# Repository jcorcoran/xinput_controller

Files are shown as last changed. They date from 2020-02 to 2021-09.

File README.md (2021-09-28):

# xinput_controller

## Installation

Getting the xinput libraries working is a bit of a process.
Last tested with the following software baslines:
  - Teensyduino 1.50: https://www.pjrc.com/teensy/td_150/TeensyduinoInstall.exe
  - Arduino 1.8.11: https://www.arduino.cc/en/main/OldSoftwareReleases
  - ArduinoXInput_Teensy 1.0.6: https://github.com/dmadison/ArduinoXInput_Teensy/releases
  - ArduinoXInput v1.2.1: https://github.com/dmadison/ArduinoXInput  (installable through ARduino Tools > Manage Libraries)
 
Follow the installation instructions for ArduinoXInput library found [in its repo](https://github.com/dmadison/ArduinoXInput_Teensy)

## PCB

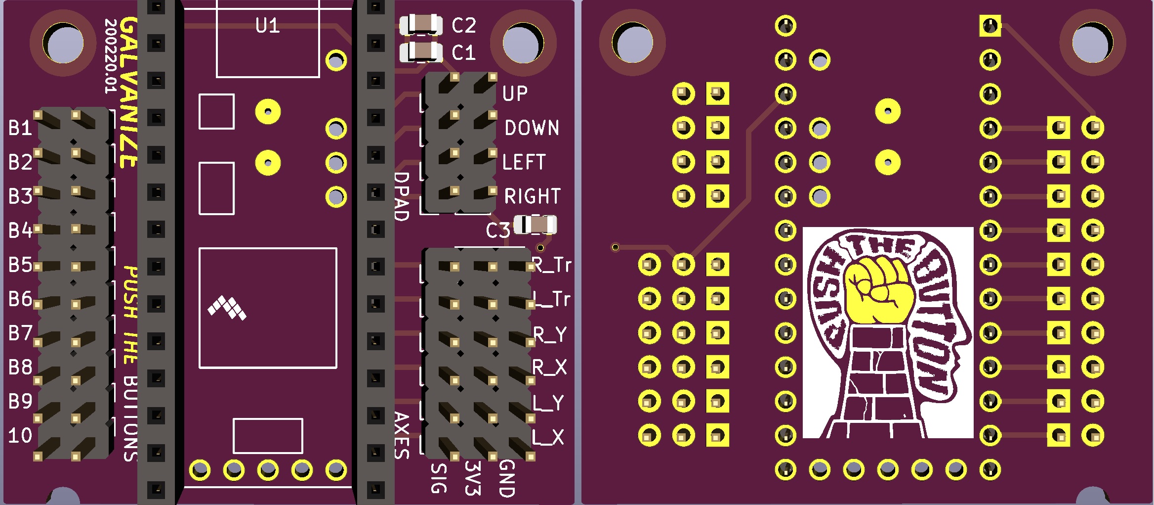
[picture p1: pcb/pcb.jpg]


* KiCAD project files and gerbers are [here](https://github.com/jcorcoran/xinput_controller/tree/master/pcb/galvanize)
* Also available for easy one-click ordering from: https://oshpark.com/shared_projects/lwcYD8mQ

Generic breakout board for a typical xinput device that provides the following on 0.1" pitch headers:
   * 10x discrete button input channels
   * 4x discrete D-Pad inputs (Up, Down, Left, Right)
   * 6x analog input channels (Right Axis X & Y, Left Axis X & Y, Left & Right Triggers)

### Bill of materials:

  * 1x - Teensy LC
  * 2x - 1x14 0.1" pitch female pin headers
  * 14x - 1x2 0.1" pitch male pin headers
  * 6x - 1x3 0.1" pitch male pin headers
  * C1, C2, C3 filter caps are optional

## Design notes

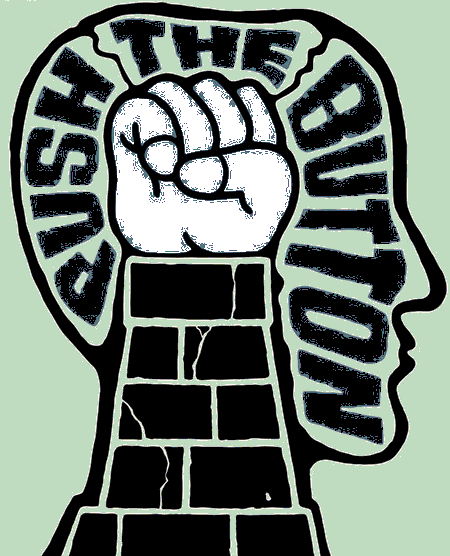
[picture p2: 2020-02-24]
pcb/galvanize/push_The_button.bmp

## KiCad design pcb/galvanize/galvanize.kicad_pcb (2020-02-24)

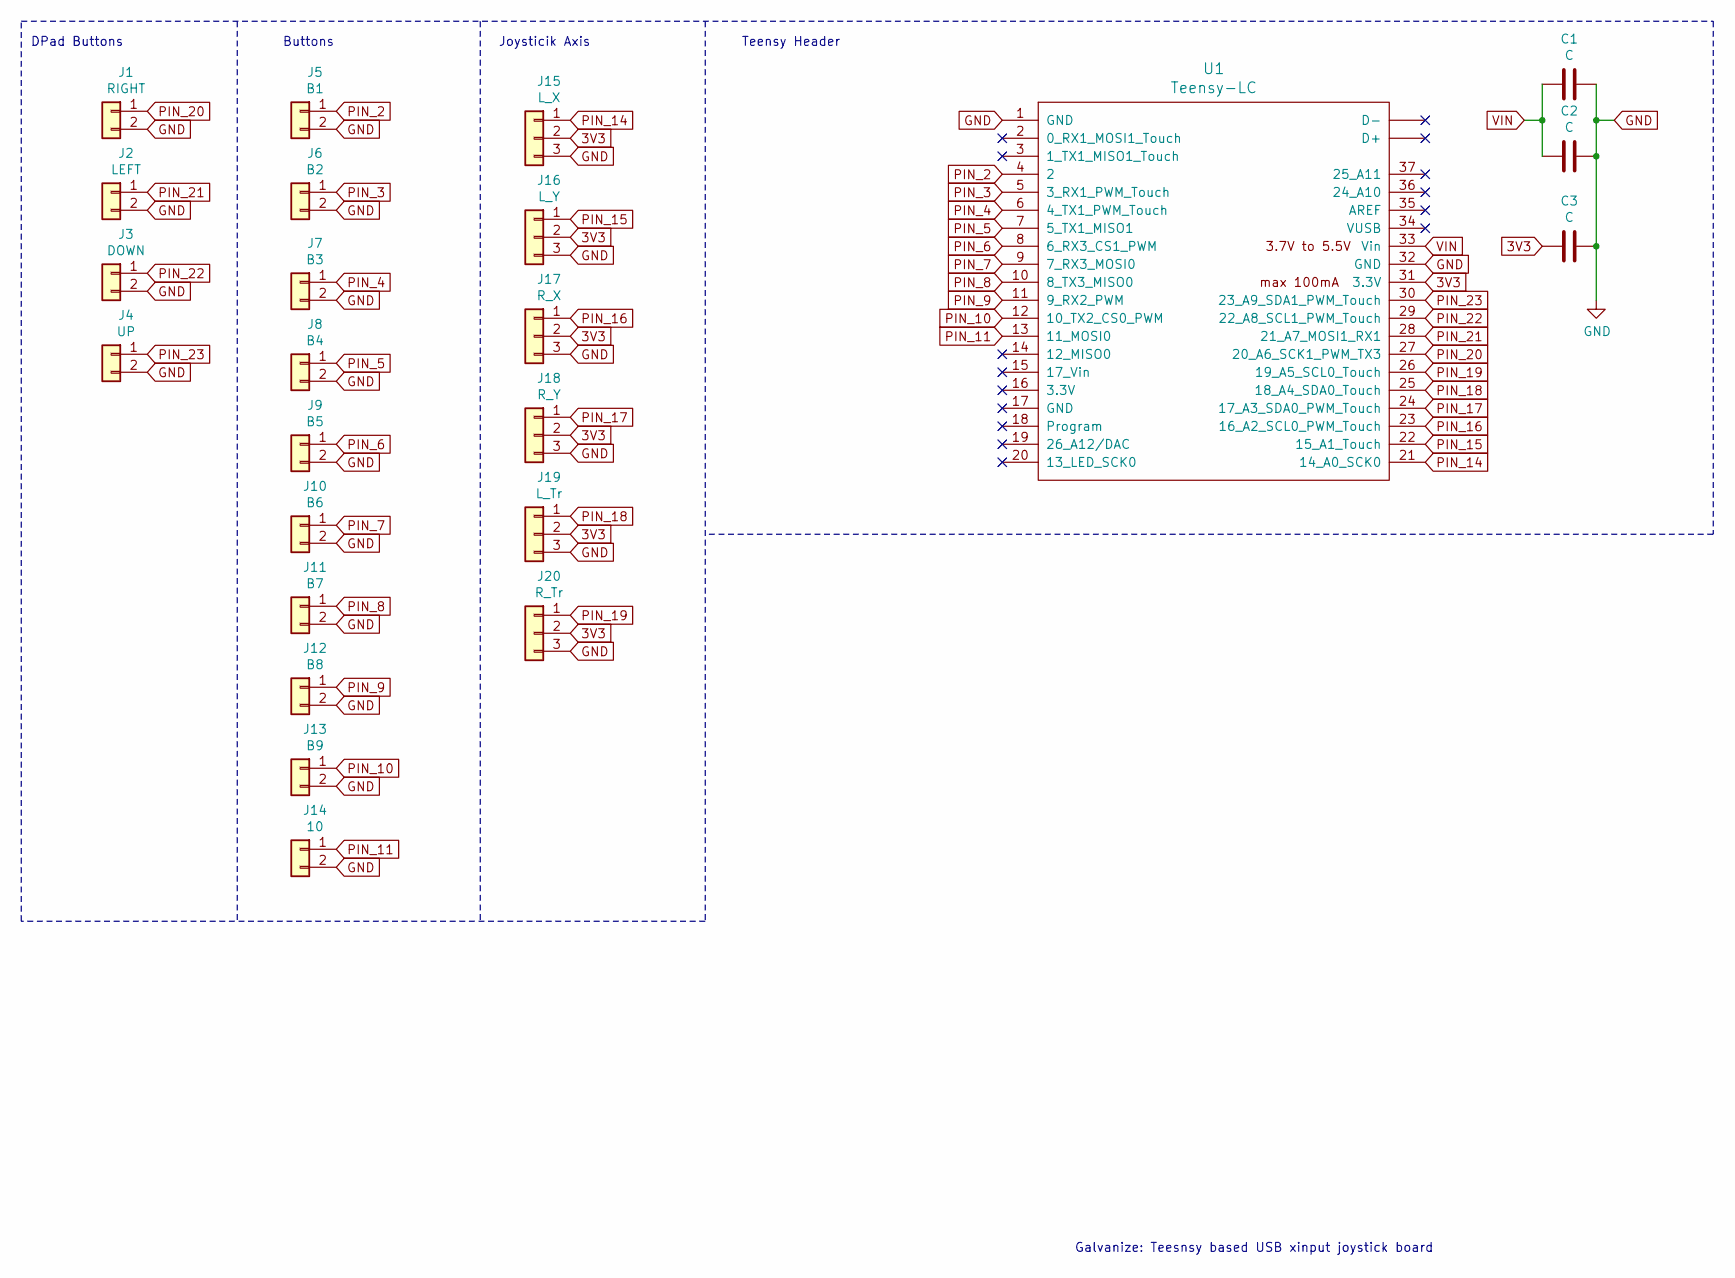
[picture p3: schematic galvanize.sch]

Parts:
C1, C2, C3: C; C_0805_2012Metric_Pad1.15x1.40mm_HandSolder
J1: RIGHT; PinHeader_1x02_P2.54mm_Vertical_Labeled
J2: LEFT; PinHeader_1x02_P2.54mm_Vertical_Labeled
J3: DOWN; PinHeader_1x02_P2.54mm_Vertical_Labeled
J4: UP; PinHeader_1x02_P2.54mm_Vertical_Labeled
J5: B1; PinHeader_1x02_P2.54mm_Vertical_Labeled
J6: B2; PinHeader_1x02_P2.54mm_Vertical_Labeled
J7: B3; PinHeader_1x02_P2.54mm_Vertical_Labeled
J8: B4; PinHeader_1x02_P2.54mm_Vertical_Labeled
J9: B5; PinHeader_1x02_P2.54mm_Vertical_Labeled
J10: B6; PinHeader_1x02_P2.54mm_Vertical_Labeled
J11: B7; PinHeader_1x02_P2.54mm_Vertical_Labeled
J12: B8; PinHeader_1x02_P2.54mm_Vertical_Labeled
J13: B9; PinHeader_1x02_P2.54mm_Vertical_Labeled
J14: 10; PinHeader_1x02_P2.54mm_Vertical_Labeled
J15: L_X; PinHeader_1x03_P2.54mm_Vertical_Labeled
J16: L_Y; PinHeader_1x03_P2.54mm_Vertical_Labeled
J17: R_X; PinHeader_1x03_P2.54mm_Vertical_Labeled
J18: R_Y; PinHeader_1x03_P2.54mm_Vertical_Labeled
J19: L_Tr; PinHeader_1x03_P2.54mm_Vertical_Labeled
J20: R_Tr; PinHeader_1x03_P2.54mm_Vertical_Labeled
U1: Teensy-LC; Teensy30_31_32_LC

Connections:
3V3: C3.2, J15.2, J16.2, J17.2, J18.2, J19.2, J20.2, U1.31 (3.3V)
GND: C1.1, C2.1, C3.1, J1.2, J2.2, J3.2, J4.2, J5.2, J6.2, J7.2, J8.2, J9.2, J10.2, J11.2, J12.2, J13.2, J14.2, J15.3, J16.3, J17.3, J18.3, J19.3, J20.3, U1.1 (GND), U1.32 (GND)
PIN_2: J5.1, U1.4 (2)
PIN_3: J6.1, U1.5 (3_RX1_PWM_Touch)
PIN_4: J7.1, U1.6 (4_TX1_PWM_Touch)
PIN_5: J8.1, U1.7 (5_TX1_MISO1)
PIN_6: J9.1, U1.8 (6_RX3_CS1_PWM)
PIN_7: J10.1, U1.9 (7_RX3_MOSI0)
PIN_8: J11.1, U1.10 (8_TX3_MISO0)
PIN_9: J12.1, U1.11 (9_RX2_PWM)
PIN_10: J13.1, U1.12 (10_TX2_CS0_PWM)
PIN_11: J14.1, U1.13 (11_MOSI0)
PIN_14: J15.1, U1.21 (14_A0_SCK0)
PIN_15: J16.1, U1.22 (15_A1_Touch)
PIN_16: J17.1, U1.23 (16_A2_SCL0_PWM_Touch)
PIN_17: J18.1, U1.24 (17_A3_SDA0_PWM_Touch)
PIN_18: J19.1, U1.25 (18_A4_SDA0_Touch)
PIN_19: J20.1, U1.26 (19_A5_SCL0_Touch)
PIN_20: J1.1, U1.27 (20_A6_SCK1_PWM_TX3)
PIN_21: J2.1, U1.28 (21_A7_MOSI1_RX1)
PIN_22: J3.1, U1.29 (22_A8_SCL1_PWM_Touch)
PIN_23: J4.1, U1.30 (23_A9_SDA1_PWM_Touch)
VIN: C1.2, C2.2, U1.33 (Vin)

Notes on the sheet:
DPad Buttons
Buttons
Joysticik Axis
Teensy Header
Galvanize: Teesnsy based USB xinput joystick board

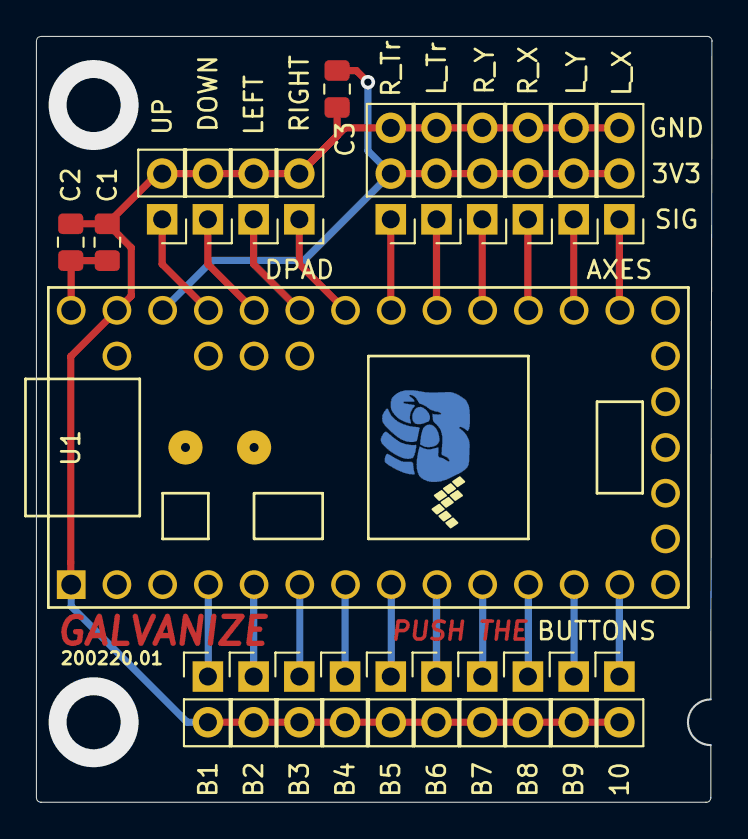
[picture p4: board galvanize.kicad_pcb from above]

Board: 2 copper layers, 37.5 x 42.5 mm, 24 parts (0 on the bottom side), 23 nets.

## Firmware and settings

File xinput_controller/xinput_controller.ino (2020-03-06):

/**
 * xinput_controller
 *
 * Intended for FRC use as a generic joystick/button box platform.
 *
 * based on flight stick example from:
 * https://github.com/dmadison/MSF-XINPUT/blob/master/MSF_XINPUT/examples/MSF_FightStick/MSF_FightStick.ino
 *
 **/

//Includes
#include <Bounce.h>
#include <XInput.h>

//General Declarations
#define MILLIDEBOUNCE 20  //Debounce time in milliseconds
#define NUMBUTTONS 14     //Number of all buttons (including d-pad)
#define NUMBUTTONSONLY 10 //Number of non-dpad buttons 

//Digital Pin Declarations
#define pinUP 23     //Up on stick pin
#define pinDN 22     //Down on stick pin
#define pinLT 21     //Left on stick pin
#define pinRT 20     //Right on stick pin
#define pinB1 2      //Button 1 pin
#define pinB2 3      //Button 2 pin
#define pinB3 4      //Button 3 pin
#define pinB4 5      //Button 4 pin
#define pinB5 6      //Button 5 pin
#define pinB6 7      //Button 6 pin
#define pinB7 8      //Button 7 pin
#define pinB8 9      //Button 8 pin
#define pinB9 10     //Select 9 pin
#define pinB10 11    //Start 10 pin
#define pinOBLED 13  //Onboard LED pin
//Analog Pin Declarations
#define pinLX 0        //Left X axis pin
#define pinLY 1        //Left Y axis pin
#define pinRX 2        //Right X axis pin
#define pinRY 3        //Right Y axis pin
#define pinLeftTrig  4 //Left trigger
#define pinRightTrig 5 //Right trigger

                                //When box is upside down
//DISABLED ANALOG INPUTS        //Left board    Right board
#define LEFT_X_DISABLED false   //true          false
#define LEFT_Y_DISABLED false   //true          false
#define RIGHT_X_DISABLED true    //false         true
#define RIGHT_Y_DISABLED true   //true          true
#define TRIGGER_DISABLED true   //true          true

#define ANALOG_RES 13     // Resolution of the analog reads (bits)

//Position of a button in the button status array
#define POSUP 0
#define POSDN 1
#define POSLT 2
#define POSRT 3
#define POSB1 4
#define POSB2 5
#define POSB3 6
#define POSB4 7
#define POSB5 8
#define POSB6 9
#define POSB7 10
#define POSB8 11
#define POSB9 12
#define POSB10 13

//Global Variables
byte buttonStatus[NUMBUTTONS];  //array Holds a "Snapshot" of the button status to parse and manipulate

//Setup Button Debouncing
Bounce joystickUP = Bounce(pinUP, MILLIDEBOUNCE);
Bounce joystickDOWN = Bounce(pinDN, MILLIDEBOUNCE);
Bounce joystickLEFT = Bounce(pinLT, MILLIDEBOUNCE);
Bounce joystickRIGHT = Bounce(pinRT, MILLIDEBOUNCE);
Bounce button1 = Bounce(pinB1, MILLIDEBOUNCE);
Bounce button2 = Bounce(pinB2, MILLIDEBOUNCE);
Bounce button3 = Bounce(pinB3, MILLIDEBOUNCE);
Bounce button4 = Bounce(pinB4, MILLIDEBOUNCE);
Bounce button5 = Bounce(pinB5, MILLIDEBOUNCE);
Bounce button6 = Bounce(pinB6, MILLIDEBOUNCE);
Bounce button7 = Bounce(pinB7, MILLIDEBOUNCE);
Bounce button8 = Bounce(pinB8, MILLIDEBOUNCE);
Bounce button9 = Bounce(pinB9, MILLIDEBOUNCE);
Bounce button10 = Bounce(pinB10, MILLIDEBOUNCE);

//void Configure Inputs and Outputs
void setupPins()
{
    //Configure the direction of the pins
    //All inputs with internal pullups enabled
    pinMode(pinUP, INPUT_PULLUP);
    pinMode(pinDN, INPUT_PULLUP);
    pinMode(pinLT, INPUT_PULLUP);
    pinMode(pinRT, INPUT_PULLUP);
    pinMode(pinB1, INPUT_PULLUP);
    pinMode(pinB2, INPUT_PULLUP);
    pinMode(pinB3, INPUT_PULLUP);
    pinMode(pinB4, INPUT_PULLUP);
    pinMode(pinB5, INPUT_PULLUP);
    pinMode(pinB6, INPUT_PULLUP);
    pinMode(pinB7, INPUT_PULLUP);
    pinMode(pinB8, INPUT_PULLUP);
    pinMode(pinB9, INPUT_PULLUP);
    pinMode(pinB10, INPUT_PULLUP);
    pinMode(pinOBLED, OUTPUT);  
    //Set the LED to low to make sure it is off
    digitalWrite(pinOBLED, LOW);
}

//Update the debounced button statuses
//We are looking for falling edges since the boards are built
//for common ground sticks
void buttonRead()
{
  if (joystickUP.update()) {buttonStatus[POSUP] = joystickUP.fallingEdge();}
  if (joystickDOWN.update()) {buttonStatus[POSDN] = joystickDOWN.fallingEdge();}
  if (joystickLEFT.update()) {buttonStatus[POSLT] = joystickLEFT.fallingEdge();}
  if (joystickRIGHT.update()) {buttonStatus[POSRT] = joystickRIGHT.fallingEdge();}
  if (button1.update()) {buttonStatus[POSB1] = button1.fallingEdge();}
  if (button2.update()) {buttonStatus[POSB2] = button2.fallingEdge();}
  if (button3.update()) {buttonStatus[POSB3] = button3.fallingEdge();}
  if (button4.update()) {buttonStatus[POSB4] = button4.fallingEdge();}
  if (button5.update()) {buttonStatus[POSB5] = button5.fallingEdge();}
  if (button6.update()) {buttonStatus[POSB6] = button6.fallingEdge();}
  if (button7.update()) {buttonStatus[POSB7] = button7.fallingEdge();}
  if (button8.update()) {buttonStatus[POSB8] = button8.fallingEdge();}
  if (button9.update()) {buttonStatus[POSB9] = button9.fallingEdge();}
  if (button10.update()) {buttonStatus[POSB10] = button10.fallingEdge();}
}

//ProcessInputs
void processInputs()
{
  int leftJoyX = pow(2,ANALOG_RES)/2;
  int leftJoyY = pow(2,ANALOG_RES)/2;
  int rightJoyX = pow(2,ANALOG_RES)/2;
  int rightJoyY = pow(2,ANALOG_RES)/2;
  int triggerLeft= 0;
  int triggerRight = 0;
  
  //Update the DPAD
  XInput.setDpad(buttonStatus[POSUP], buttonStatus[POSDN], buttonStatus[POSLT], buttonStatus[POSRT]);

  //Buttons
  XInput.setButton(BUTTON_A, buttonStatus[POSB1]);
  XInput.setButton(BUTTON_B, buttonStatus[POSB2]);
  XInput.setButton(BUTTON_X, buttonStatus[POSB3]);
  XInput.setButton(BUTTON_Y, buttonStatus[POSB4]);
  XInput.setButton(BUTTON_LB, buttonStatus[POSB5]);
  XInput.setButton(BUTTON_RB, buttonStatus[POSB6]);
  XInput.setButton(BUTTON_BACK, buttonStatus[POSB7]);
  XInput.setButton(BUTTON_START, buttonStatus[POSB8]);
  XInput.setButton(BUTTON_L3, buttonStatus[POSB9]);
  XInput.setButton(BUTTON_R3, buttonStatus[POSB10]);
  
  //Axes
  if(!LEFT_X_DISABLED) {
    leftJoyX = analogRead(pinLX);
  }
  if(!LEFT_Y_DISABLED) {
    leftJoyY = analogRead(pinLY);
  }
  if(!RIGHT_X_DISABLED) {
    rightJoyX = analogRead(pinRX);
  }
  if(!RIGHT_Y_DISABLED) {
    rightJoyY = analogRead(pinRY);
  }
  if(!TRIGGER_DISABLED) {
    triggerLeft  = analogRead(pinLeftTrig);
    triggerRight = analogRead(pinRightTrig);
  }


  XInput.setJoystick(JOY_RIGHT, rightJoyX, rightJoyY);
  XInput.setJoystick(JOY_LEFT, leftJoyX, leftJoyY);  
  // Set the trigger values as analog
  XInput.setTrigger(TRIGGER_LEFT, triggerLeft);
  XInput.setTrigger(TRIGGER_RIGHT, triggerRight);

}

//Setup
void setup() 
{
  //Increase resolution of analog inputs.
  analogReadResolution(ANALOG_RES);

  XInput.setJoystickRange(0, pow(2,ANALOG_RES));  // Set joystick range to the ADC
  XInput.setAutoSend(false);  // Wait for all controls before sending

  XInput.begin();
  
  setupPins();
}

void loop() 
{
  //Poll Buttons
  buttonRead();
  
  //Process all inputs and load up the usbData registers correctly
  processInputs();

  //Update the LED display
  //controller.LEDUpdate();

  //Send data
  XInput.send();

  //Receive data
  //controller.receiveXinput();
}

/**
 * Scale the analog inputs to the range used by joystick trigger function.
 * 
 * Note each axis only operates over half the range (0 - 3V)
 *   left trigger is the low side of the range (0 - 1.5V)
 *   right trigger is the high side of the range (1.5 - 3V)
 */
//int xinput_scale_trigger(int val) {
//  int _out_max = 0xFF;
//  int _out_min = 0;
//  int _in_min = 0;
//  int _in_max = pow(2,ANALOG_RES);
//  int _in_zero = (_in_max - _in_min)/2;
//  int ret = 0;
//
//  if(val >= _in_zero) { //Scale the high side
//    ret = map(val, _in_zero, _in_max, 0, _out_max);
//  } else {  //Scale the low side
//    ret = map(val, _in_min, _in_zero, _out_min, 0);
//  }
//
//  return ret;
//}

/**
 * Scale the analog inputs to the range used by joystick function.
 *
 */
//int xinput_scale_sticks(int val) {
//  int _out_max = 32767;
//  int _out_min = -32768;
//  int _in_min = 0;
//  int _in_max = pow(2,ANALOG_RES);
//  int _in_zero = (_in_max - _in_min)/2;
//  int ret = 0;
//
//  if(val >= _in_zero) { //Scale the high side
//    ret = map(val, _in_zero, _in_max, 0, _out_max);
//  } else {  //Scale the low side
//    ret = map(val, _in_min, _in_zero, _out_min, 0);
//  }
//  
//  return ret;
//}

int avgAnalogRead(int channel) {
  #define SAMPLES 5
  int average = 0;

  for(int i=0; i < SAMPLES; i++) {
    average += analogRead(channel);
  }

  return average / SAMPLES;
}

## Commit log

2019-03-05 Create xinput.cpp
    Removed "SOCD cleaner" feature which prevents hitting multiple DPAD values simultaneously.
    Don't filter the DPAD values at all on the controller end
    https://github.com/dmadison/MSF-XINPUT/commit/a636230b351761e78916faf3afa97afc56bffac0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
2019-03-06 Update xinput_controller.ino
    Add L3 and R3 buttons.
    Add axis
    Map buttons so pin increases with order on smart dashboard.
2020-02-18 Initial commit of PCB files.
    [galvanize.kicad_pcb, galvanize.sch]
2020-02-20 Add pcb files to repo.
    [galvanize.sch]
2020-02-24 Add PCB and code updates for prelim release. Buttons and two axes tested working on TeensyLC.
    [galvanize.kicad_pcb, galvanize.sch]
2021-09-28 Add PCB notes
2021-09-28 add pcb image
